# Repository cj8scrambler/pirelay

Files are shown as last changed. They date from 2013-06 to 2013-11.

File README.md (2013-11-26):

pirelay
=======

pirelay is a small add-on board for the [Raspberry Pi](http://www.raspberrypi.org/) for up to 9 temperature controlled relays.  The board's relays are controlled by WS2801 LED drivers which allow for PWM output.  Each relay be a [small on circuit](http://www.allelectronics.com/make-a-store/item/SRLY-19/1A-SOLID-STATE-RELAY-3-8VDC-CONTROL/1.html) relay or a [larger off circuit SSR](http://www.allelectronics.com/make-a-store/item/SRLY-50/50-AMP-SOLID-STATE-RELAY/1.html).  A network of Maxim [One Wire Bus temperature sensors](http://www.maximintegrated.com/datasheet/index.mvp/id/2812) can be connected and assigned to each relay.  The temperature control algorithm can be set to PID, ON/OFF (with compressor delay) or manual mode.

All control and monitoring is done through a web interface.  Temperature and power output data is logged to an SQlite3 database for viewing history charts.

The board is designed for homebrew beer fermentation temperature control but can be easily adapted to other uses.  For beer fermentation a single chest freezer and up to 8 individual fermenters can be controlled from 1 pirelay.

Status
------
As of November 2013 the project is in an early development phase.  The 3rd version of the board ([v2.0d](http://oshpark.com/shared_projects/q5iLnXZY)) has been arrived, but needs to be assembled.  The basic framework of the code is in place to read temp sensors, control relays with PWM, log data to a database and provide a basic API for a more advanced web front end.

Still need to implement true PID mode, move configuration from hardcoding to web interface, build web interface for viewing historical data.

License
-------
The hardware schematic and layout files (Eagle PCB) are included in the repo and licensed under [CERN OHL v.1.1](http://ohwr.org/cernohl)

The software for pirelay is licensed under [Apache License, Version 2.0](http://www.apache.org/licenses/LICENSE-2.0.html)

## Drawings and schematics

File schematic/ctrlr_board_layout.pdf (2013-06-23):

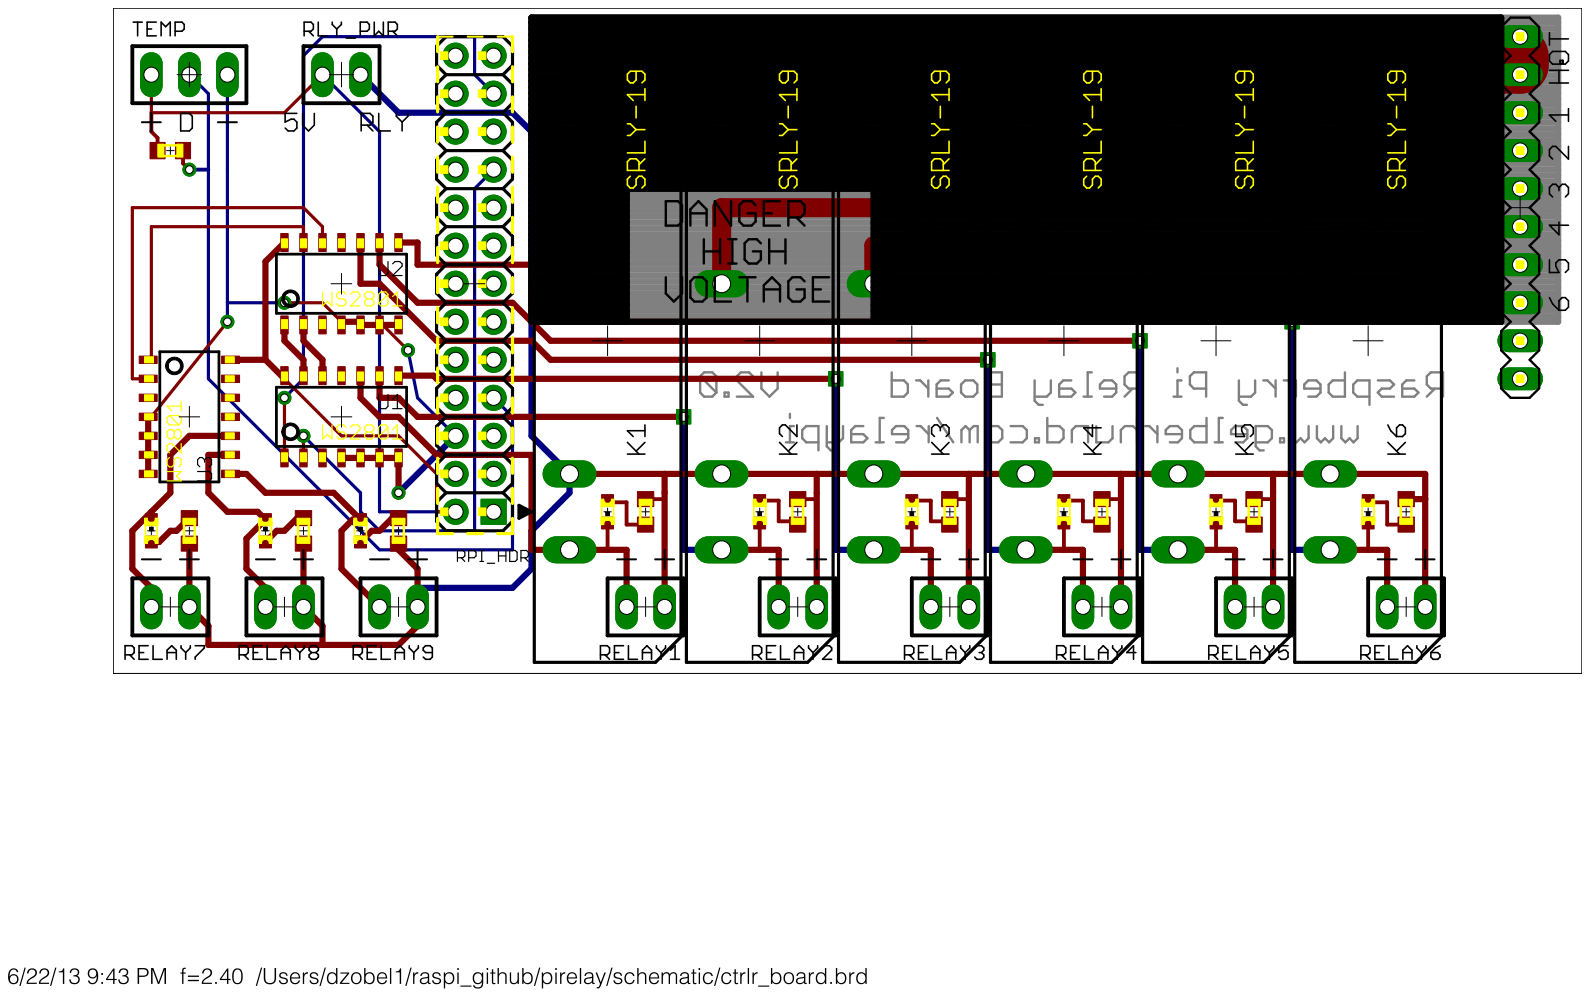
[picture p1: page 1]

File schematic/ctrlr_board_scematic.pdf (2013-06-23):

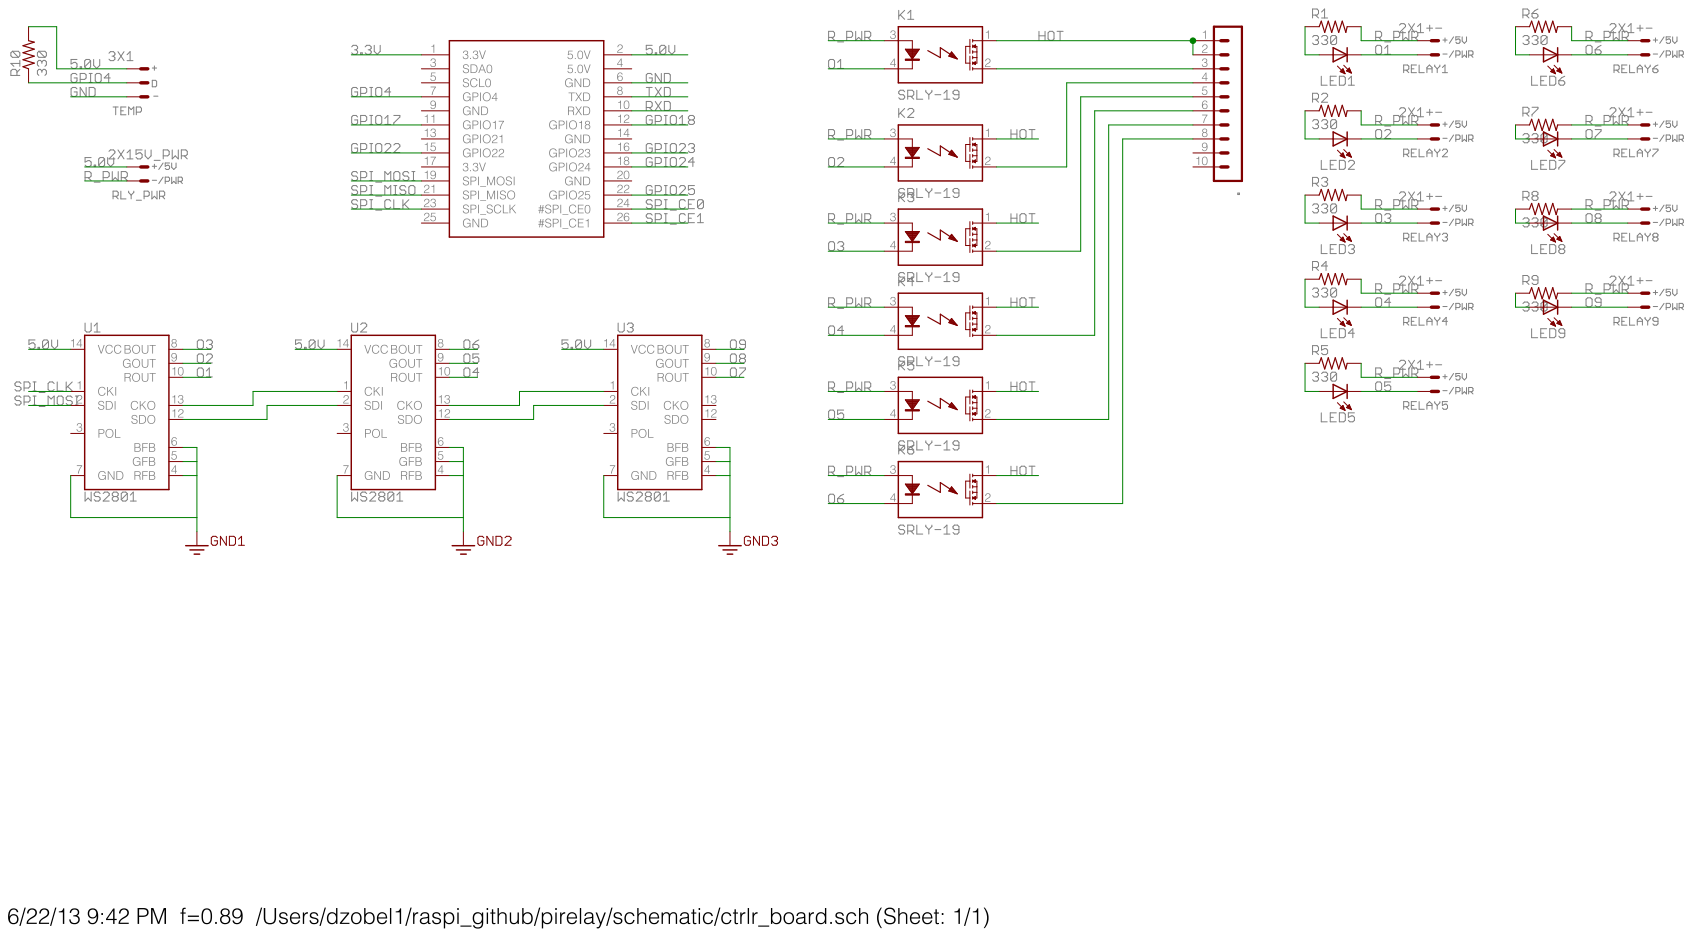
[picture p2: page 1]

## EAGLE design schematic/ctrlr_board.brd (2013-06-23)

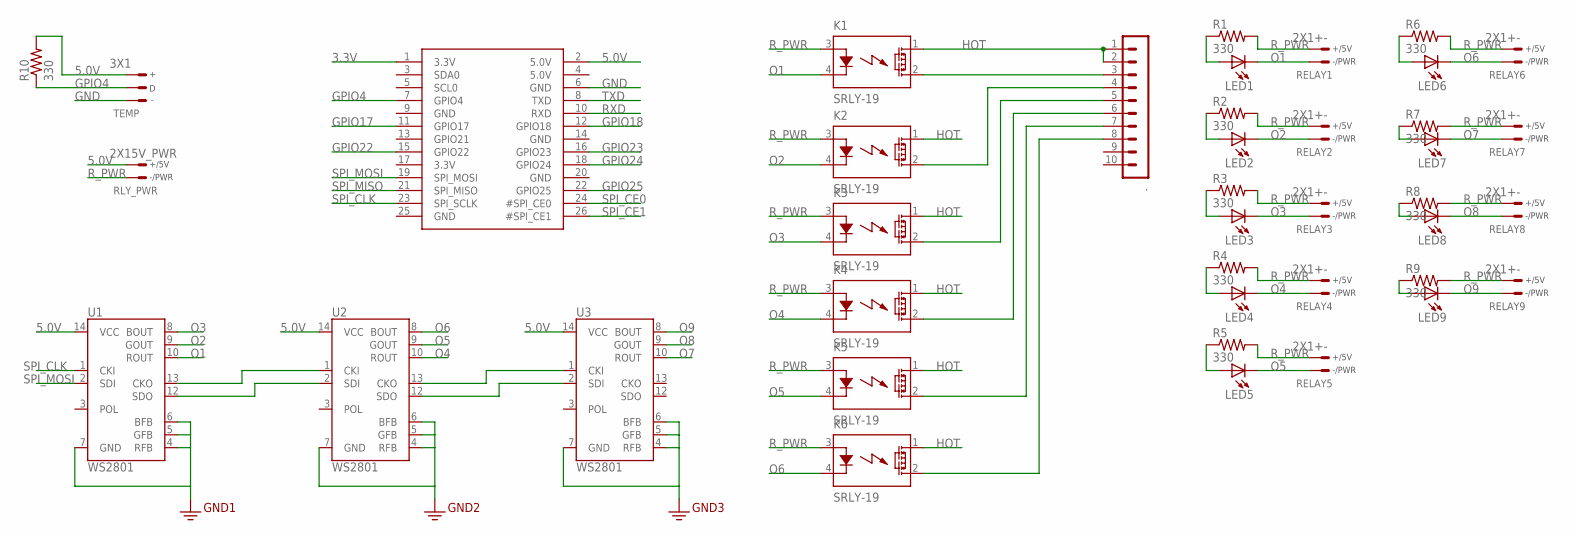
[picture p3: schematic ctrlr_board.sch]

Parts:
.: 10X1; HDR10
K1, K2, K3, K4, K5, K6: SRLY-19; OAC5
LED1, LED2, LED3, LED4, LED5, LED6, LED7, LED8, LED9: LED; LED0603
R1, R2, R3, R4, R5, R6, R7, R8, R9, R10: 330; R0603
RELAY1, RELAY2, RELAY3, RELAY4, RELAY5, RELAY6, RELAY7, RELAY8, RELAY9: 2X1+-; HDR2
RLY_PWR: 2X15V_PWR; HDR2_5V_PWR
RPI_HDR: RASPBERRY_PI_HEADERRASPI_HDR; RASPBERRY_PI_HEADER
TEMP: 3X1; HDR3
U1, U2, U3: WS2801; SOP-14

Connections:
3.3V: RPI_HDR.1 (3.3V)
5.0V: R10.2, RLY_PWR.+, RPI_HDR.2 (5.0V), TEMP.+, U1.14 (VCC), U2.14 (VCC), U3.14 (VCC)
GND: RPI_HDR.6 (GND), TEMP.-, U1.4 (RFB), U1.5 (GFB), U1.6 (BFB), U1.7 (GND), U2.4 (RFB), U2.5 (GFB), U2.6 (BFB), U2.7 (GND), U3.4 (RFB), U3.5 (GFB), U3.6 (BFB), U3.7 (GND)
GPIO4: R10.1, RPI_HDR.7 (GPIO4), TEMP.D
GPIO17: RPI_HDR.11 (GPIO17)
GPIO18: RPI_HDR.12 (GPIO18)
GPIO22: RPI_HDR.15 (GPIO22)
GPIO23: RPI_HDR.16 (GPIO23)
GPIO24: RPI_HDR.18 (GPIO24)
GPIO25: RPI_HDR.22 (GPIO25)
HOT: ..1, ..2, K1.1 (D1), K2.1 (D1), K3.1 (D1), K4.1 (D1), K5.1 (D1), K6.1 (D1)
unnamed: LED1.A, R1.1
unnamed: LED2.A, R2.1
unnamed: LED3.A, R3.1
unnamed: LED4.A, R4.1
unnamed: LED6.A, R6.1
unnamed: LED5.A, R5.1
unnamed: ..4, K2.2 (D2)
unnamed: ..5, K3.2 (D2)
unnamed: ..6, K4.2 (D2)
unnamed: ..7, K5.2 (D2)
unnamed: ..8, K6.2 (D2)
unnamed: ..3, K1.2 (D2)
unnamed: LED7.A, R7.1
unnamed: LED8.A, R8.1
unnamed: U1.13 (CKO), U2.1 (CKI)
unnamed: U1.12 (SDO), U2.2 (SDI)
unnamed: U2.12 (SDO), U3.2 (SDI)
unnamed: U2.13 (CKO), U3.1 (CKI)
unnamed: LED9.A, R9.1
O1: K1.4 (K), LED1.C, RELAY1.-, U1.10 (ROUT)
O2: K2.4 (K), LED2.C, RELAY2.-, U1.9 (GOUT)
O3: K3.4 (K), LED3.C, RELAY3.-, U1.8 (BOUT)
O4: K4.4 (K), LED4.C, RELAY4.-, U2.10 (ROUT)
O5: K5.4 (K), LED5.C, RELAY5.-, U2.9 (GOUT)
O6: K6.4 (K), LED6.C, RELAY6.-, U2.8 (BOUT)
O7: LED7.C, RELAY7.-, U3.10 (ROUT)
O8: LED8.C, RELAY8.-, U3.9 (GOUT)
O9: LED9.C, RELAY9.-, U3.8 (BOUT)
RXD: RPI_HDR.10 (RXD)
R_PWR: K1.3 (A), K2.3 (A), K3.3 (A), K4.3 (A), K5.3 (A), K6.3 (A), R1.2, R2.2, R3.2, R4.2, R5.2, R6.2, R7.2, R8.2, R9.2, RELAY1.+, RELAY2.+, RELAY3.+, RELAY4.+, RELAY5.+, RELAY6.+, RELAY7.+, RELAY8.+, RELAY9.+, RLY_PWR.-
SPI_CE0: RPI_HDR.24 (#SPI_CE0)
SPI_CE1: RPI_HDR.26 (#SPI_CE1)
SPI_CLK: RPI_HDR.23 (SPI_SCLK), U1.1 (CKI)
SPI_MISO: RPI_HDR.21 (SPI_MISO)
SPI_MOSI: RPI_HDR.19 (SPI_MOSI), U1.2 (SDI)
TXD: RPI_HDR.8 (TXD)

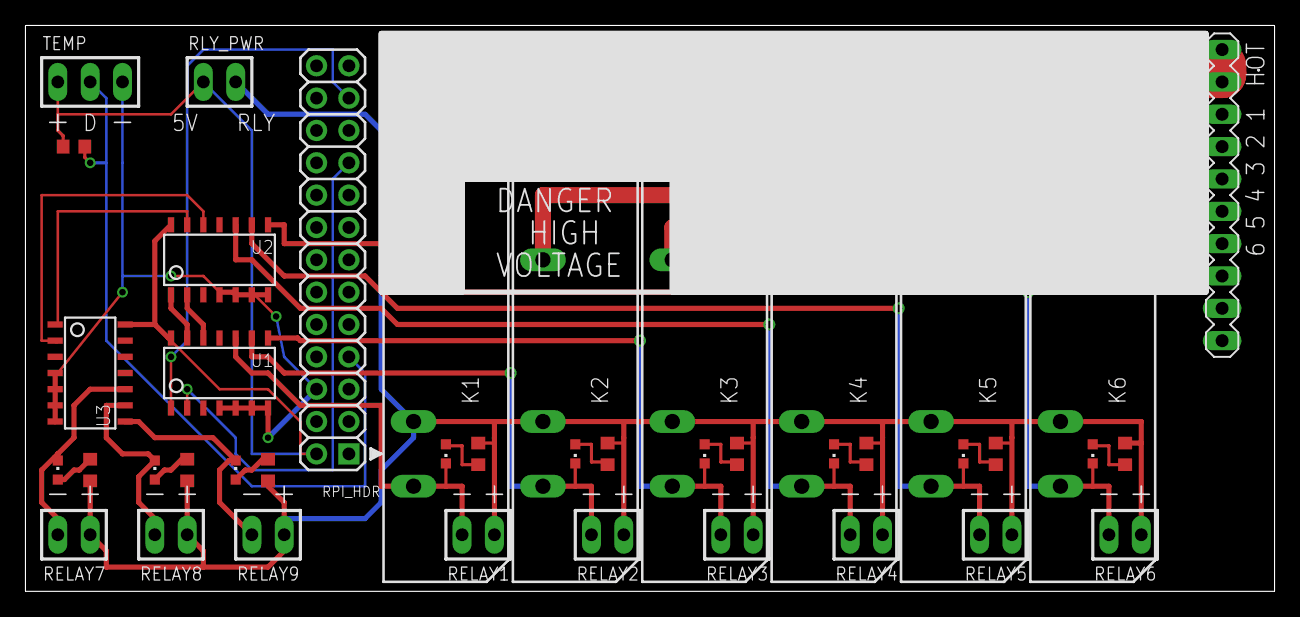
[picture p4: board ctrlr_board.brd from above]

Board: 2 copper layers, 98.1 x 44.4 mm, 41 parts (0 on the bottom side), 35 nets.

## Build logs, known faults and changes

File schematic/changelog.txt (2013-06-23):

v1.0
  Released 11/22/12
  Recieved 12/15/12
  Initial layout

v1.1
  Flip rpi header so expansion board swings over rpi
  darlington array drives gnd (not +5)

v2.0
  Released 6/22/12
  Ordered 3 from oshpark.com
  Replace darlington array with 3 WS2801 to do PWM in hardware
  Add 9th relay output
  silkscreen high voltage area
  Add pullup on one wire bus

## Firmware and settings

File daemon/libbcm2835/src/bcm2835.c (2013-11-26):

// bcm2835.c
// C and C++ support for Broadcom BCM 2835 as used in Raspberry Pi
// http://elinux.org/RPi_Low-level_peripherals
// http://www.raspberrypi.org/wp-content/uploads/2012/02/BCM2835-ARM-Peripherals.pdf
//
// Author: Mike McCauley
// Copyright (C) 2011-2013 Mike McCauley
// $Id: bcm2835.c,v 1.12 2013/09/01 00:56:56 mikem Exp mikem $

#include <stdlib.h>
#include <stdio.h>
#include <errno.h>
#include <fcntl.h>
#include <sys/mman.h>
#include <string.h>
#include <time.h>
#include <unistd.h>

#include "bcm2835.h"

// This define enables a little test program (by default a blinking output on pin RPI_GPIO_PIN_11)
// You can do some safe, non-destructive testing on any platform with:
// gcc bcm2835.c -D BCM2835_TEST
// ./a.out
//#define BCM2835_TEST

// Uncommenting this define compiles alternative I2C code for the version 1 RPi
// The P1 header I2C pins are connected to SDA0 and SCL0 on V1.
// By default I2C code is generated for the V2 RPi which has SDA1 and SCL1 connected.
// #define I2C_V1

// Pointers to the hardware register bases
volatile uint32_t *bcm2835_gpio = MAP_FAILED;
volatile uint32_t *bcm2835_pwm  = MAP_FAILED;
volatile uint32_t *bcm2835_clk  = MAP_FAILED;
volatile uint32_t *bcm2835_pads = MAP_FAILED;
volatile uint32_t *bcm2835_spi0 = MAP_FAILED;
volatile uint32_t *bcm2835_bsc0 = MAP_FAILED;
volatile uint32_t *bcm2835_bsc1 = MAP_FAILED;
volatile uint32_t *bcm2835_st	= MAP_FAILED;


// This variable allows us to test on hardware other than RPi.
// It prevents access to the kernel memory, and does not do any peripheral access
// Instead it prints out what it _would_ do if debug were 0
static uint8_t debug = 0;

// I2C The time needed to transmit one byte. In microseconds.
static int i2c_byte_wait_us = 0;

//
// Low level register access functions
//

void  bcm2835_set_debug(uint8_t d)
{
    debug = d;
}

// safe read from peripheral
uint32_t bcm2835_peri_read(volatile uint32_t* paddr)
{
    if (debug)
    {
//        printf("bcm2835_peri_read  paddr %08X\n", (unsigned) paddr);
	return 0;
    }
    else
    {
	// Make sure we dont return the _last_ read which might get lost
	// if subsequent code changes to a different peripheral
	uint32_t ret = *paddr;
	*paddr; // Read without assigneing to an unused variable
	return ret;
    }
}

// read from peripheral without the read barrier
uint32_t bcm2835_peri_read_nb(volatile uint32_t* paddr)
{
    if (debug)
    {
//	printf("bcm2835_peri_read_nb  paddr %08X\n", (unsigned) paddr);
	return 0;
    }
    else
    {
	return *paddr;
    }
}

// safe write to peripheral
void bcm2835_peri_write(volatile uint32_t* paddr, uint32_t value)
{
  if (debug)
    {
//	printf("bcm2835_peri_write paddr %08X, value %08X\n", (unsigned) paddr, value);
    }
  else
    {
	// Make sure we don't rely on the first write, which may get
	// lost if the previous access was to a different peripheral.
	*paddr = value;
	*paddr = value;
    }
}

// write to peripheral without the write barrier
void bcm2835_peri_write_nb(volatile uint32_t* paddr, uint32_t value)
{
    if (debug)
    {
//	printf("bcm2835_peri_write_nb paddr %08X, value %08X\n",
//               (unsigned) paddr, value);
    }
    else
    {
	*paddr = value;
    }
}

// Set/clear only the bits in value covered by the mask
void bcm2835_peri_set_bits(volatile uint32_t* paddr, uint32_t value, uint32_t mask)
{
    uint32_t v = bcm2835_peri_read(paddr);
    v = (v & ~mask) | (value & mask);
    bcm2835_peri_write(paddr, v);
}

//
// Low level convenience functions
//

// Function select
// pin is a BCM2835 GPIO pin number NOT RPi pin number
//      There are 6 control registers, each control the functions of a block
//      of 10 pins.
//      Each control register has 10 sets of 3 bits per GPIO pin:
//
//      000 = GPIO Pin X is an input
//      001 = GPIO Pin X is an output
//      100 = GPIO Pin X takes alternate function 0
//      101 = GPIO Pin X takes alternate function 1
//      110 = GPIO Pin X takes alternate function 2
//      111 = GPIO Pin X takes alternate function 3
//      011 = GPIO Pin X takes alternate function 4
//      010 = GPIO Pin X takes alternate function 5
//
// So the 3 bits for port X are:
//      X / 10 + ((X % 10) * 3)
void bcm2835_gpio_fsel(uint8_t pin, uint8_t mode)
{
    // Function selects are 10 pins per 32 bit word, 3 bits per pin
    volatile uint32_t* paddr = bcm2835_gpio + BCM2835_GPFSEL0/4 + (pin/10);
    uint8_t   shift = (pin % 10) * 3;
    uint32_t  mask = BCM2835_GPIO_FSEL_MASK << shift;
    uint32_t  value = mode << shift;
    bcm2835_peri_set_bits(paddr, value, mask);
}

// Set output pin
void bcm2835_gpio_set(uint8_t pin)
{
    volatile uint32_t* paddr = bcm2835_gpio + BCM2835_GPSET0/4 + pin/32;
    uint8_t shift = pin % 32;
    bcm2835_peri_write(paddr, 1 << shift);
}

// Clear output pin
void bcm2835_gpio_clr(uint8_t pin)
{
    volatile uint32_t* paddr = bcm2835_gpio + BCM2835_GPCLR0/4 + pin/32;
    uint8_t shift = pin % 32;
    bcm2835_peri_write(paddr, 1 << shift);
}

// Set all output pins in the mask
void bcm2835_gpio_set_multi(uint32_t mask)
{
    volatile uint32_t* paddr = bcm2835_gpio + BCM2835_GPSET0/4;
    bcm2835_peri_write(paddr, mask);
}

// Clear all output pins in the mask
void bcm2835_gpio_clr_multi(uint32_t mask)
{
    volatile uint32_t* paddr = bcm2835_gpio + BCM2835_GPCLR0/4;
    bcm2835_peri_write(paddr, mask);
}

// Read input pin
uint8_t bcm2835_gpio_lev(uint8_t pin)
{
    volatile uint32_t* paddr = bcm2835_gpio + BCM2835_GPLEV0/4 + pin/32;
    uint8_t shift = pin % 32;
    uint32_t value = bcm2835_peri_read(paddr);
    return (value & (1 << shift)) ? HIGH : LOW;
}

// See if an event detection bit is set
// Sigh cant support interrupts yet
uint8_t bcm2835_gpio_eds(uint8_t pin)
{
    volatile uint32_t* paddr = bcm2835_gpio + BCM2835_GPEDS0/4 + pin/32;
    uint8_t shift = pin % 32;
    uint32_t value = bcm2835_peri_read(paddr);
    return (value & (1 << shift)) ? HIGH : LOW;
}

// Write a 1 to clear the bit in EDS
void bcm2835_gpio_set_eds(uint8_t pin)
{
    volatile uint32_t* paddr = bcm2835_gpio + BCM2835_GPEDS0/4 + pin/32;
    uint8_t shift = pin % 32;
    uint32_t value = 1 << shift;
    bcm2835_peri_write(paddr, value);
}

// Rising edge detect enable
void bcm2835_gpio_ren(uint8_t pin)
{
    volatile uint32_t* paddr = bcm2835_gpio + BCM2835_GPREN0/4 + pin/32;
    uint8_t shift = pin % 32;
    uint32_t value = 1 << shift;
    bcm2835_peri_set_bits(paddr, value, value);
}
void bcm2835_gpio_clr_ren(uint8_t pin)
{
    volatile uint32_t* paddr = bcm2835_gpio + BCM2835_GPREN0/4 + pin/32;
    uint8_t shift = pin % 32;
    uint32_t value = 1 << shift;
    bcm2835_peri_set_bits(paddr, 0, value);
}

// Falling edge detect enable
void bcm2835_gpio_fen(uint8_t pin)
{
    volatile uint32_t* paddr = bcm2835_gpio + BCM2835_GPFEN0/4 + pin/32;
    uint8_t shift = pin % 32;
    uint32_t value = 1 << shift;
    bcm2835_peri_set_bits(paddr, value, value);
}
void bcm2835_gpio_clr_fen(uint8_t pin)
{
    volatile uint32_t* paddr = bcm2835_gpio + BCM2835_GPFEN0/4 + pin/32;
    uint8_t shift = pin % 32;
    uint32_t value = 1 << shift;
    bcm2835_peri_set_bits(paddr, 0, value);
}

// High detect enable
void bcm2835_gpio_hen(uint8_t pin)
{
    volatile uint32_t* paddr = bcm2835_gpio + BCM2835_GPHEN0/4 + pin/32;
    uint8_t shift = pin % 32;
    uint32_t value = 1 << shift;
    bcm2835_peri_set_bits(paddr, value, value);
}
void bcm2835_gpio_clr_hen(uint8_t pin)
{
    volatile uint32_t* paddr = bcm2835_gpio + BCM2835_GPHEN0/4 + pin/32;
    uint8_t shift = pin % 32;
    uint32_t value = 1 << shift;
    bcm2835_peri_set_bits(paddr, 0, value);
}

// Low detect enable
void bcm2835_gpio_len(uint8_t pin)
{
    volatile uint32_t* paddr = bcm2835_gpio + BCM2835_GPLEN0/4 + pin/32;
    uint8_t shift = pin % 32;
    uint32_t value = 1 << shift;
    bcm2835_peri_set_bits(paddr, value, value);
}
void bcm2835_gpio_clr_len(uint8_t pin)
{
    volatile uint32_t* paddr = bcm2835_gpio + BCM2835_GPLEN0/4 + pin/32;
    uint8_t shift = pin % 32;
    uint32_t value = 1 << shift;
    bcm2835_peri_set_bits(paddr, 0, value);
}

// Async rising edge detect enable
void bcm2835_gpio_aren(uint8_t pin)
{
    volatile uint32_t* paddr = bcm2835_gpio + BCM2835_GPAREN0/4 + pin/32;
    uint8_t shift = pin % 32;
    uint32_t value = 1 << shift;
    bcm2835_peri_set_bits(paddr, value, value);
}
void bcm2835_gpio_clr_aren(uint8_t pin)
{
    volatile uint32_t* paddr = bcm2835_gpio + BCM2835_GPAREN0/4 + pin/32;
    uint8_t shift = pin % 32;
    uint32_t value = 1 << shift;
    bcm2835_peri_set_bits(paddr, 0, value);
}

// Async falling edge detect enable
void bcm2835_gpio_afen(uint8_t pin)
{
    volatile uint32_t* paddr = bcm2835_gpio + BCM2835_GPAFEN0/4 + pin/32;
    uint8_t shift = pin % 32;
    uint32_t value = 1 << shift;
    bcm2835_peri_set_bits(paddr, value, value);
}
void bcm2835_gpio_clr_afen(uint8_t pin)
{
    volatile uint32_t* paddr = bcm2835_gpio + BCM2835_GPAFEN0/4 + pin/32;
    uint8_t shift = pin % 32;
    uint32_t value = 1 << shift;
    bcm2835_peri_set_bits(paddr, 0, value);
}

// Set pullup/down
void bcm2835_gpio_pud(uint8_t pud)
{
    volatile uint32_t* paddr = bcm2835_gpio + BCM2835_GPPUD/4;
    bcm2835_peri_write(paddr, pud);
}

// Pullup/down clock
// Clocks the value of pud into the GPIO pin
void bcm2835_gpio_pudclk(uint8_t pin, uint8_t on)
{
    volatile uint32_t* paddr = bcm2835_gpio + BCM2835_GPPUDCLK0/4 + pin/32;
    uint8_t shift = pin % 32;
    bcm2835_peri_write(paddr, (on ? 1 : 0) << shift);
}

// Read GPIO pad behaviour for groups of GPIOs
uint32_t bcm2835_gpio_pad(uint8_t group)
{
    volatile uint32_t* paddr = bcm2835_pads + BCM2835_PADS_GPIO_0_27/4 + group*2;
    return bcm2835_peri_read(paddr);
}

// Set GPIO pad behaviour for groups of GPIOs
// powerup value for al pads is
// BCM2835_PAD_SLEW_RATE_UNLIMITED | BCM2835_PAD_HYSTERESIS_ENABLED | BCM2835_PAD_DRIVE_8mA
void bcm2835_gpio_set_pad(uint8_t group, uint32_t control)
{
    volatile uint32_t* paddr = bcm2835_pads + BCM2835_PADS_GPIO_0_27/4 + group*2;
    bcm2835_peri_write(paddr, control | BCM2835_PAD_PASSWRD);
}

// Some convenient arduino-like functions
// milliseconds
void bcm2835_delay(unsigned int millis)
{
    struct timespec sleeper;
    
    sleeper.tv_sec  = (time_t)(millis / 1000);
    sleeper.tv_nsec = (long)(millis % 1000) * 1000000;
    nanosleep(&sleeper, NULL);
}

// microseconds
void bcm2835_delayMicroseconds(uint64_t micros)
{
    struct timespec t1;
    uint64_t        start;
	
    // Calling nanosleep() takes at least 100-200 us, so use it for
    // long waits and use a busy wait on the System Timer for the rest.
    start =  bcm2835_st_read();
    
    if (micros > 450)
    {
	t1.tv_sec = 0;
	t1.tv_nsec = 1000 * (long)(micros - 200);
	nanosleep(&t1, NULL);
    }    
  
    bcm2835_st_delay(start, micros);
}

//
// Higher level convenience functions
//

// Set the state of an output
void bcm2835_gpio_write(uint8_t pin, uint8_t on)
{
    if (on)
	bcm2835_gpio_set(pin);
    else
	bcm2835_gpio_clr(pin);
}

// Set the state of a all 32 outputs in the mask to on or off
void bcm2835_gpio_write_multi(uint32_t mask, uint8_t on)
{
    if (on)
	bcm2835_gpio_set_multi(mask);
    else
	bcm2835_gpio_clr_multi(mask);
}

// Set the state of a all 32 outputs in the mask to the values in value
void bcm2835_gpio_write_mask(uint32_t value, uint32_t mask)
{
    bcm2835_gpio_set_multi(value & mask);
    bcm2835_gpio_clr_multi((~value) & mask);
}

// Set the pullup/down resistor for a pin
//
// The GPIO Pull-up/down Clock Registers control the actuation of internal pull-downs on
// the respective GPIO pins. These registers must be used in conjunction with the GPPUD
// register to effect GPIO Pull-up/down changes. The following sequence of events is
// required:
// 1. Write to GPPUD to set the required control signal (i.e. Pull-up or Pull-Down or neither
// to remove the current Pull-up/down)
// 2. Wait 150 cycles ? this provides the required set-up time for the control signal
// 3. Write to GPPUDCLK0/1 to clock the control signal into the GPIO pads you wish to
// modify ? NOTE only the pads which receive a clock will be modified, all others will
// retain their previous state.
// 4. Wait 150 cycles ? this provides the required hold time for the control signal
// 5. Write to GPPUD to remove the control signal
// 6. Write to GPPUDCLK0/1 to remove the clock
//
// RPi has P1-03 and P1-05 with 1k8 pullup resistor
void bcm2835_gpio_set_pud(uint8_t pin, uint8_t pud)
{
    bcm2835_gpio_pud(pud);
    delayMicroseconds(10);
    bcm2835_gpio_pudclk(pin, 1);
    delayMicroseconds(10);
    bcm2835_gpio_pud(BCM2835_GPIO_PUD_OFF);
    bcm2835_gpio_pudclk(pin, 0);
}

void bcm2835_spi_begin(void)
{
    // Set the SPI0 pins to the Alt 0 function to enable SPI0 access on them
    bcm2835_gpio_fsel(RPI_GPIO_P1_26, BCM2835_GPIO_FSEL_ALT0); // CE1
    bcm2835_gpio_fsel(RPI_GPIO_P1_24, BCM2835_GPIO_FSEL_ALT0); // CE0
    bcm2835_gpio_fsel(RPI_GPIO_P1_21, BCM2835_GPIO_FSEL_ALT0); // MISO
    bcm2835_gpio_fsel(RPI_GPIO_P1_19, BCM2835_GPIO_FSEL_ALT0); // MOSI
    bcm2835_gpio_fsel(RPI_GPIO_P1_23, BCM2835_GPIO_FSEL_ALT0); // CLK
    
    // Set the SPI CS register to the some sensible defaults
    volatile uint32_t* paddr = bcm2835_spi0 + BCM2835_SPI0_CS/4;
    bcm2835_peri_write(paddr, 0); // All 0s
    
    // Clear TX and RX fifos
    bcm2835_peri_write_nb(paddr, BCM2835_SPI0_CS_CLEAR);
}

void bcm2835_spi_end(void)
{  
    // Set all the SPI0 pins back to input
    bcm2835_gpio_fsel(RPI_GPIO_P1_26, BCM2835_GPIO_FSEL_INPT); // CE1
    bcm2835_gpio_fsel(RPI_GPIO_P1_24, BCM2835_GPIO_FSEL_INPT); // CE0
    bcm2835_gpio_fsel(RPI_GPIO_P1_21, BCM2835_GPIO_FSEL_INPT); // MISO
    bcm2835_gpio_fsel(RPI_GPIO_P1_19, BCM2835_GPIO_FSEL_INPT); // MOSI
    bcm2835_gpio_fsel(RPI_GPIO_P1_23, BCM2835_GPIO_FSEL_INPT); // CLK
}

void bcm2835_spi_setBitOrder(uint8_t order)
{
    // BCM2835_SPI_BIT_ORDER_MSBFIRST is the only one suported by SPI0
}

// defaults to 0, which means a divider of 65536.
// The divisor must be a power of 2. Odd numbers
// rounded down. The maximum SPI clock rate is
// of the APB clock
void bcm2835_spi_setClockDivider(uint16_t divider)
{
    volatile uint32_t* paddr = bcm2835_spi0 + BCM2835_SPI0_CLK/4;
    bcm2835_peri_write(paddr, divider);
}

void bcm2835_spi_setDataMode(uint8_t mode)
{
    volatile uint32_t* paddr = bcm2835_spi0 + BCM2835_SPI0_CS/4;
    // Mask in the CPO and CPHA bits of CS
    bcm2835_peri_set_bits(paddr, mode << 2, BCM2835_SPI0_CS_CPOL | BCM2835_SPI0_CS_CPHA);
}

// Writes (and reads) a single byte to SPI
uint8_t bcm2835_spi_transfer(uint8_t value)
{
    volatile uint32_t* paddr = bcm2835_spi0 + BCM2835_SPI0_CS/4;
    volatile uint32_t* fifo = bcm2835_spi0 + BCM2835_SPI0_FIFO/4;

    if (debug)
    {
        return 0;
    }

    // This is Polled transfer as per section 10.6.1
    // BUG ALERT: what happens if we get interupted in this section, and someone else
    // accesses a different peripheral? 
    // Clear TX and RX fifos
    bcm2835_peri_set_bits(paddr, BCM2835_SPI0_CS_CLEAR, BCM2835_SPI0_CS_CLEAR);

    // Set TA = 1
    bcm2835_peri_set_bits(paddr, BCM2835_SPI0_CS_TA, BCM2835_SPI0_CS_TA);

    // Maybe wait for TXD
    while (!(bcm2835_peri_read(paddr) & BCM2835_SPI0_CS_TXD))
	;

    // Write to FIFO, no barrier
    bcm2835_peri_write_nb(fifo, value);

    // Wait for DONE to be set
    while (!(bcm2835_peri_read_nb(paddr) & BCM2835_SPI0_CS_DONE))
	;

    // Read any byte that was sent back by the slave while we sere sending to it
    uint32_t ret = bcm2835_peri_read_nb(fifo);

    // Set TA = 0, and also set the barrier
    bcm2835_peri_set_bits(paddr, 0, BCM2835_SPI0_CS_TA);

    return ret;
}

// Writes (and reads) an number of bytes to SPI
void bcm2835_spi_transfernb(char* tbuf, char* rbuf, uint32_t len)
{
    volatile uint32_t* paddr = bcm2835_spi0 + BCM2835_SPI0_CS/4;
    volatile uint32_t* fifo = bcm2835_spi0 + BCM2835_SPI0_FIFO/4;

    if (debug)
    {
        return;
    }

    // This is Polled transfer as per section 10.6.1
    // BUG ALERT: what happens if we get interupted in this section, and someone else
    // accesses a different peripheral? 

    // Clear TX and RX fifos
    bcm2835_peri_set_bits(paddr, BCM2835_SPI0_CS_CLEAR, BCM2835_SPI0_CS_CLEAR);

    // Set TA = 1
    bcm2835_peri_set_bits(paddr, BCM2835_SPI0_CS_TA, BCM2835_SPI0_CS_TA);

    uint32_t i;
    for (i = 0; i < len; i++)
    {
	// Maybe wait for TXD
	while (!(bcm2835_peri_read(paddr) & BCM2835_SPI0_CS_TXD))
	    ;

	// Write to FIFO, no barrier
	bcm2835_peri_write_nb(fifo, tbuf[i]);

	// Wait for RXD
	while (!(bcm2835_peri_read(paddr) & BCM2835_SPI0_CS_RXD))
	    ;

	// then read the data byte
	rbuf[i] = bcm2835_peri_read_nb(fifo);
    }
    // Wait for DONE to be set
    while (!(bcm2835_peri_read_nb(paddr) & BCM2835_SPI0_CS_DONE))
	;

    // Set TA = 0, and also set the barrier
    bcm2835_peri_set_bits(paddr, 0, BCM2835_SPI0_CS_TA);
}

// Writes an number of bytes to SPI
void bcm2835_spi_writenb(char* tbuf, uint32_t len)
{
    volatile uint32_t* paddr = bcm2835_spi0 + BCM2835_SPI0_CS/4;
    volatile uint32_t* fifo = bcm2835_spi0 + BCM2835_SPI0_FIFO/4;

    // This is Polled transfer as per section 10.6.1
    // BUG ALERT: what happens if we get interupted in this section, and someone else
    // accesses a different peripheral?

    // Clear TX and RX fifos
    bcm2835_peri_set_bits(paddr, BCM2835_SPI0_CS_CLEAR, BCM2835_SPI0_CS_CLEAR);

    // Set TA = 1
    bcm2835_peri_set_bits(paddr, BCM2835_SPI0_CS_TA, BCM2835_SPI0_CS_TA);

    uint32_t i;
    for (i = 0; i < len; i++)
    {
	// Maybe wait for TXD
	while (!(bcm2835_peri_read(paddr) & BCM2835_SPI0_CS_TXD))
	    ;
	
	// Write to FIFO, no barrier
	bcm2835_peri_write_nb(fifo, tbuf[i]);
	
	// Read from FIFO to prevent stalling
	while (bcm2835_peri_read(paddr) & BCM2835_SPI0_CS_RXD)
	    (void) bcm2835_peri_read_nb(fifo);
    }
    
    // Wait for DONE to be set
    while (!(bcm2835_peri_read_nb(paddr) & BCM2835_SPI0_CS_DONE)) {
	while (bcm2835_peri_read(paddr) & BCM2835_SPI0_CS_RXD)
		(void) bcm2835_peri_read_nb(fifo);
    };

    // Set TA = 0, and also set the barrier
    bcm2835_peri_set_bits(paddr, 0, BCM2835_SPI0_CS_TA);
}

// Writes (and reads) an number of bytes to SPI
// Read bytes are copied over onto the transmit buffer
void bcm2835_spi_transfern(char* buf, uint32_t len)
{
    bcm2835_spi_transfernb(buf, buf, len);
}

void bcm2835_spi_chipSelect(uint8_t cs)
{
    volatile uint32_t* paddr = bcm2835_spi0 + BCM2835_SPI0_CS/4;
    // Mask in the CS bits of CS
    bcm2835_peri_set_bits(paddr, cs, BCM2835_SPI0_CS_CS);
}

void bcm2835_spi_setChipSelectPolarity(uint8_t cs, uint8_t active)
{
    volatile uint32_t* paddr = bcm2835_spi0 + BCM2835_SPI0_CS/4;
    uint8_t shift = 21 + cs;
    // Mask in the appropriate CSPOLn bit
    bcm2835_peri_set_bits(paddr, active << shift, 1 << shift);
}

void bcm2835_i2c_begin(void)
{
#ifdef I2C_V1
    volatile uint32_t* paddr = bcm2835_bsc0 + BCM2835_BSC_DIV/4;
    // Set the I2C/BSC0 pins to the Alt 0 function to enable I2C access on them
    bcm2835_gpio_fsel(RPI_GPIO_P1_03, BCM2835_GPIO_FSEL_ALT0); // SDA
    bcm2835_gpio_fsel(RPI_GPIO_P1_05, BCM2835_GPIO_FSEL_ALT0); // SCL
#else
    volatile uint32_t* paddr = bcm2835_bsc1 + BCM2835_BSC_DIV/4;
    // Set the I2C/BSC1 pins to the Alt 0 function to enable I2C access on them
    bcm2835_gpio_fsel(RPI_V2_GPIO_P1_03, BCM2835_GPIO_FSEL_ALT0); // SDA
    bcm2835_gpio_fsel(RPI_V2_GPIO_P1_05, BCM2835_GPIO_FSEL_ALT0); // SCL
#endif    

    // Read the clock divider register
    uint16_t cdiv = bcm2835_peri_read(paddr);
    // Calculate time for transmitting one byte
    // 1000000 = micros seconds in a second
    // 9 = Clocks per byte : 8 bits + ACK
    i2c_byte_wait_us = ((float)cdiv / BCM2835_CORE_CLK_HZ) * 1000000 * 9;
}

void bcm2835_i2c_end(void)
{
#ifdef I2C_V1
    // Set all the I2C/BSC0 pins back to input
    bcm2835_gpio_fsel(RPI_GPIO_P1_03, BCM2835_GPIO_FSEL_INPT); // SDA
    bcm2835_gpio_fsel(RPI_GPIO_P1_05, BCM2835_GPIO_FSEL_INPT); // SCL
#else
    // Set all the I2C/BSC1 pins back to input
    bcm2835_gpio_fsel(RPI_V2_GPIO_P1_03, BCM2835_GPIO_FSEL_INPT); // SDA
    bcm2835_gpio_fsel(RPI_V2_GPIO_P1_05, BCM2835_GPIO_FSEL_INPT); // SCL
#endif
}
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
int main(int argc, char **argv)
{
    // Be non-destructive
    bcm2835_set_debug(1);

    if (!bcm2835_init())
	return 1;

    // Configure some GPIO pins fo some testing
    // Set RPI pin P1-11 to be an output
    bcm2835_gpio_fsel(RPI_GPIO_P1_11, BCM2835_GPIO_FSEL_OUTP);
    // Set RPI pin P1-15 to be an input
    bcm2835_gpio_fsel(RPI_GPIO_P1_15, BCM2835_GPIO_FSEL_INPT);
    //  with a pullup
    bcm2835_gpio_set_pud(RPI_GPIO_P1_15, BCM2835_GPIO_PUD_UP);
    // And a low detect enable
    bcm2835_gpio_len(RPI_GPIO_P1_15);
    // and input hysteresis disabled on GPIOs 0 to 27
    bcm2835_gpio_set_pad(BCM2835_PAD_GROUP_GPIO_0_27, BCM2835_PAD_SLEW_RATE_UNLIMITED|BCM2835_PAD_DRIVE_8mA);

#if 1
    // Blink
    while (1)
    {
	// Turn it on
	bcm2835_gpio_write(RPI_GPIO_P1_11, HIGH);
	
	// wait a bit
	bcm2835_delay(500);
	
	// turn it off
	bcm2835_gpio_write(RPI_GPIO_P1_11, LOW);
	
	// wait a bit
	bcm2835_delay(500);
    }
#endif

#if 0
    // Read input
    while (1)
    {
	// Read some data
	uint8_t value = bcm2835_gpio_lev(RPI_GPIO_P1_15);
	printf("read from pin 15: %d\n", value);
	
	// wait a bit
	bcm2835_delay(500);
    }
#endif

#if 0
    // Look for a low event detection
    // eds will be set whenever pin 15 goes low
    while (1)
    {
	if (bcm2835_gpio_eds(RPI_GPIO_P1_15))
	{
	    // Now clear the eds flag by setting it to 1
	    bcm2835_gpio_set_eds(RPI_GPIO_P1_15);
	    printf("low event detect for pin 15\n");
	}

	// wait a bit
	bcm2835_delay(500);
    }
#endif

    if (!bcm2835_close())
	return 1;

    return 0;
}
#endif

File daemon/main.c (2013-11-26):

#include <stdio.h>
#include <unistd.h>
#include <stdlib.h>
#include <signal.h>
#include <sys/time.h>

#include <bcm2835.h>

#include "ctrlr.h"
#include "log.h"
#include "control_output.h"
#include "temp_reader.h"
#include "dataserver.h"

int global_debug = ERROR;
static int quit = 0;

static void cleanup(int signum) {

  extern struct system_data sysdata;
  ERROR("Shutting Down\n");

  quit = 1;
  dataserver_stop(&sysdata);
  log_cleanup(&sysdata);
  output_disable_all(sysdata.nodes);
  bcm2835_close();
}

static void handle_kill(int signum) {
  ERROR("Caught kill signal\n");
  cleanup(signum);
  exit(-1);
}

static void timer_handler(int sig, siginfo_t *si, void *uc) {
  struct system_data *sysdata = si->si_value.sival_ptr;

  struct timeval current;
  struct timeval delta = {0};
  static struct timeval next_temp_time = {0};
  static int temp_overflow = 0;
  static struct timeval next_log_time = {0};
  static int log_overflow = 0;

  gettimeofday(&current, NULL);

  /* Read the temp sensors if it's been long enough */
  if (!timercmp(&current, &next_temp_time, <)) {
    temp_timer_handler(sysdata);

    /* check for overflow */
    timersub(&current, &next_temp_time, &delta);
    if ((delta.tv_sec * 1000 + delta.tv_usec / 1000) > TIMER_BASE_PERIOD) {
      DEBUG("temp reader timer overflow: %.3f secs (#%d)\n", 
            (delta.tv_sec + delta.tv_usec / 1000000.0), ++temp_overflow);
    }
    delta.tv_sec = TEMP_SAMPLE_RATE / 1000;
    delta.tv_usec = (TEMP_SAMPLE_RATE * 1000) % 1000000;
    timeradd(&current, &delta, &next_temp_time);
  }

  /* Log data if it's been long enough */
  if (!timercmp(&current, &next_log_time, <)) {
    log_timer_handler(sysdata);

    /* check for overflow */
    timersub(&current, &next_log_time, &delta);
    if ((delta.tv_sec * 1000 + delta.tv_usec / 1000) > TIMER_BASE_PERIOD) {
      DEBUG("log timer overflow: %.3f secs (#%d)\n", 
            (delta.tv_sec + delta.tv_usec / 1000000.0), ++log_overflow);
    }
    delta.tv_sec = LOG_RATE / 1000;
    delta.tv_usec = (LOG_RATE * 1000) % 1000000;
    timeradd(&current, &delta, &next_log_time);
  }

}

static int hw_init(struct node_data *nodes) {

  if (system("grep -q BCM2708 /proc/cpuinfo")) {
    /* For hardware other than Raspberry Pi, use debug mode */
    bcm2835_set_debug(1);
  }

  if (!bcm2835_init()) {
    ERROR("Could not initialize bcm2835 library.\nTry running as root\n");
    return(-1);
  }

  update_outputs(nodes);

  return 0;
}

int get_trippoint(struct node_data *node, enum power_state state)
{
  if (state == OFF)
    return (node->setting.setpoint);
  else if (state == ON) {
    if (node->setting.mode == HEAT)
      return (node->setting.setpoint - node->setting.range);
    else if (node->setting.mode == COOL)
      return (node->setting.setpoint + node->setting.range);
    else
      ERROR("%s has invalid mode: %d\n", node->name, node->setting.mode);
  } else
    ERROR("%s has invalid state: %d\n", node->name, node->setting.setpoint);

   return -1;
}

void set_node_output(struct node_data *node, enum power_state state)
{
  time_t deltatime;

  if (node->setting.type == COMPRESSOR) {
    deltatime = time(NULL) - node->output.lasttime;
    if (deltatime < node->setting.min_compressor_time)
      return;
  }

  if (state == ON)
    node->output.power = 0xFF;
  else
    node->output.power = 0x00;

  node->output.lasttime = time(NULL);
}

int main(int argc, char **argv){
  int i;

  extern struct system_data sysdata;

  struct sigevent sev;
  struct itimerspec its;
  struct sigaction sa;
  timer_t timerid;

  // Try to cleanup on kill signals
  signal(SIGHUP, handle_kill);
  signal(SIGINT, handle_kill);
  signal(SIGTERM, handle_kill);

ERROR("Start\n");
  if (hw_init(sysdata.nodes))
    cleanup(-1);
  if (log_init(&sysdata))
    cleanup(-1);

  sa.sa_flags = SA_SIGINFO;
  sa.sa_sigaction = timer_handler;
  sigemptyset(&sa.sa_mask);
  sigaction(SIGUSR1, &sa, NULL);

  sev.sigev_notify = SIGEV_SIGNAL;
  sev.sigev_signo = SIGUSR1;
  sev.sigev_value.sival_ptr = &sysdata;
  timer_create(CLOCK_REALTIME, &sev, &timerid);

  its.it_value.tv_sec = (TIMER_BASE_PERIOD) / 1000;
  its.it_value.tv_nsec = (TIMER_BASE_PERIOD % 1000) * 1000000;
  its.it_interval.tv_sec = its.it_value.tv_sec;
  its.it_interval.tv_nsec = its.it_value.tv_nsec;

  INFO("Starting base timer for every %f seconds\n",
         (double)its.it_value.tv_sec + its.it_value.tv_nsec/1000000000.0);
    timer_settime(timerid, 0, &its, NULL);

  if (dataserver_start(&sysdata)) {
    ERROR("Could not start data server\n");
    cleanup(-1);
  }

  while (!quit) {
    for (i=0; i<NUM_NODES; i++){

      if (sysdata.nodes[i].setting.type == PID){
//        sysdata.nodes[i].output.power= pid(sysdata.nodes[i].temp.average);
      }
      else if ((sysdata.nodes[i].setting.type == ON_OFF) ||
               (sysdata.nodes[i].setting.type == COMPRESSOR)) {
        if (sysdata.nodes[i].setting.mode == HEAT) {
          if ((sysdata.nodes[i].temp.lowpass_reading < get_trippoint(&sysdata.nodes[i], ON)) &&
              (!power_is_on(&sysdata.nodes[i])))
                set_node_output(&sysdata.nodes[i], ON);
          if ((sysdata.nodes[i].temp.lowpass_reading > get_trippoint(&sysdata.nodes[i], OFF)) &&
              (power_is_on(&sysdata.nodes[i])))
                set_node_output(&sysdata.nodes[i], OFF);
        } else if (sysdata.nodes[i].setting.mode == COOL) {
          if ((sysdata.nodes[i].temp.lowpass_reading > get_trippoint(&sysdata.nodes[i], ON)) &&
              (!power_is_on(&sysdata.nodes[i])))
                set_node_output(&sysdata.nodes[i], ON);
          if ((sysdata.nodes[i].temp.lowpass_reading < get_trippoint(&sysdata.nodes[i], OFF)) &&
              (power_is_on(&sysdata.nodes[i])))
                set_node_output(&sysdata.nodes[i], OFF);
        }
      }
    }
//update_outputs(sysdata.nodes);
  }

  timer_delete(&timerid);
  cleanup(0);

  return 0;
}

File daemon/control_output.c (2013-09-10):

#include <stdio.h>
#include <unistd.h>
#include <pthread.h> 
#include <stdlib.h>
#include <sys/time.h>
#include <time.h>
#include <bcm2835.h>

#include "ctrlr.h"

enum power_state power_is_on(struct node_data *data)
{
  return (data->output.state);
}

int update_outputs(struct node_data *data) {

  int i;
  char spi_data[NUM_NODES];

  bcm2835_spi_begin();
  bcm2835_spi_setBitOrder(BCM2835_SPI_BIT_ORDER_MSBFIRST);
  bcm2835_spi_setDataMode(BCM2835_SPI_MODE0);
  bcm2835_spi_setClockDivider(BCM2835_SPI_CLOCK_DIVIDER_256); /* 1MHz */
  bcm2835_spi_chipSelect(BCM2835_SPI_CS0);
  bcm2835_spi_setChipSelectPolarity(BCM2835_SPI_CS0, LOW);
  DEBUG("outputs:");
  for (i=0; i< NUM_NODES; i++) {
    if (data[i].output.state == OFF)
      spi_data[i] = 0;
    else
      spi_data[i] = data[i].output.power;
    DEBUG_DUMP("  0x%02x", data[i].output.power);
 
  }
  DEBUG_DUMP("\n");
  bcm2835_spi_transfern(spi_data, NUM_NODES);
  bcm2835_spi_end();
  return 0;
}

void output_disable_all(struct node_data *data){
  int i;

  for (i=0; i< NUM_NODES; i++){
    data[i].output.state = OFF;
  }
  update_outputs(data);
}

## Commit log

2013-02-20 Remove threading, add DB permissions check, enable httpd
    Moved to single thread to fix temp reading contention issues.
    PWM from software is not reliable even with a high priority thread,
    so it will need to move to hardware control. For now it's
    handled from the main thread which causes some latency when
    there is scheduling starvation like durring high load or I/O
    operations.
    DB directory is now world r/w/x and DB file is world
    readable. Hopefully this will fix the contention issues with
    simultaneous read access from apache.
    Re-enabled the http server in the daemon on port 8888.
    [control_output.c]
2013-04-02 1st pass implementation
    Initial Framework
    -makefile
    -spawn 3 threads
    *temp reader
    *output controller
    *data server
    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
2013-04-02 Seperate timer signals and add system_settings
    Temp conversion is broken
    [control_output.c, main.c]
2013-04-02 Add Eagle schematics
    Also rearrange files
    [ctrlr_board.brd, ctrlr_board.sch]
2013-04-02 V1.0 of relay board
    [ctrlr_board.brd, ctrlr_board.sch]
2013-04-02 Version 1.1 of expansion board
    * Rotated header 180 so expansion board sits over Rpi
    * re-wired relays to switch GND via darlingtons
    * Added optional SMD LEDs to relays 1-6 for testing
    [ctrlr_board.brd, ctrlr_board.sch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]
2013-04-02 Version 1.1b of expansion board
    * v. 1.1 failed batchpcb DRC.
    * Re-did layout by hand
    * Added larger solder pads on relays
    [ctrlr_board.brd, ctrlr_board.sch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]
2013-04-02 Version 1.1c of expansion board
    * v. 1.1b failed batchpcb DRC (SFE DRC rules were the problem)
    [ctrlr_board.brd, ctrlr_board.sch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]
2013-06-20 Re-write output control for V2 hardware
    Move PWM output control from host software implementation to
    WS2801 LED driver chips which were added on V2 hardware.
2013-06-22 Framework added for REST API
    An empty framework was added for a RESTful API. This will be used
    by a web GUI (or other client) to configure, and monitor the system.
2013-06-23 Board updates for V2.0 hardware
    BatchPCB went out of business so switching to oshpark.com.
    Removed gerber files since they aren't needed there. V2.0 has
    the following changes:
    * Replace darlington array with 3 WS2801 to do PWM in hardware
    * Add 9th relay output
    * silkscreen high voltage area
    * Add pullup on one wire bus
    [ctrlr_board.brd, ctrlr_board.sch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]
2013-11-26 Support for non Raspberry Pi machines
    Add support for building and running on any linux machine, not just
    Raspberry Pi hardware. Since the relay hardware can't exist on a PC,
    no valid data will be received or logged. However, this allows work
    on the UI and interface APIs.
    * Upgrade libbcm2835 to v. 1.33
    * libbcm2835: Skip SPI functions in debug mode
    * Use libbcm2835 debug mode for non RPi hardware
    * Minor updates about V2 HW in README and config.h
    [bcm2835.c, blink.c, event.c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]

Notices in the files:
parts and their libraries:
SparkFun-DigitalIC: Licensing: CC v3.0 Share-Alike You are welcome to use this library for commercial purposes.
